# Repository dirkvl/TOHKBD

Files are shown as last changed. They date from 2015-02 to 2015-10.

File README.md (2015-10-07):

# TOHKBD rev2

## History

When Jolla announced their [Jolla phone](https://www.youtube.com/watch?v=tRZxM9rNyZ4) the mobile Linux community rejoiced and finally had a place to go from their N8x, N900, N950 or N9. Together with the new operating system on the inside, the OtherHalf concept was introduced. With direct data-connection into the phone it is now possible to extend the functionality on a hardware level.

Naturally, a keyboard OtherHalf was the [most requested feature](http://www.jollatides.com/2013/10/03/other-half-lets-prioritise/) by the community by far. Jolla however was still getting started and getting their phone launched with the minimum of Sailors at the time. This was left to the community to develop.

In [June 2013](http://talk.maemo.org/showthread.php?t=91535) one idiot thought he could easily make this -how hard could it be, really?- and started on his journey. After some time this foolish individual make TOHKBD-rev1: hackish, ugly, frankensteined, terrible durability and way too much work to assemble. But it worked. 

After this project ended there was a period of other Funky-TOH development, with during that time a lot of requests of making more keyboards. Little did they knew that in the background the imfamous 'dirkvl' together with his trusty 'kimmoli' were cooking up a new version. A better one. The One.

With an [open application](https://twitter.com/andrewzhilin/status/493485714798313472) on the hashweb/tweetspace Andrew joined the team and provid himself to be the missing piece of the three piece puzzle. With a complete team, a solid design and a strong backing from the rest of the community, the TOHKBD-team set out onto the open crowdfunding sea. [And struck gold.](https://www.kickstarter.com/projects/2028347278/tohkbd-the-other-half-keyboard-for-your-jolla)

## Hardware

### Electronics

#### TOH-cover

In the cover that snap onto the phone there is very little going on. There is a PCB that connects to all [6 pogo-pins](https://jolla.com/the-other-half-developer-kit/). Connecting to these pins is a [voltage regulator](https://github.com/dirkvl/TOHKBD/tree/master/Eagle/pics/MCP1703.jpg) and an EEPROM. 

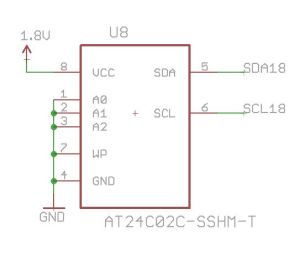
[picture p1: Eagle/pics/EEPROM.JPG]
EEPROM


This is a memory module that contains a [Vendor and Product ID](https://wiki.merproject.org/wiki/The_other_half). The phone reads this EEPROM when it connects to start the appropriate driver.

If the driver is not installed, the phone reads the [NFC tag](http://www.nfcnetstore.com/SMARTRAC+Midas+NTAG203+12x19+mm+clear+%28NFC+Forum+Type+2%29/p/121/) on the PCB and pulls the driver from the store.

With two contact pads (8mm PCBs) the keyboard piece can make contact, all 6 pins are available.

#### Keyboard piece

In the keyboard a little more is going on. The main driver is the [TCA8424](http://www.ti.com/product/TCA8424/description). It runs on 1.8V I2C lines and has three notification LEDs connected, where the TCA8424 acts as an open drain. The LEDs have some probing pads for testing during production.

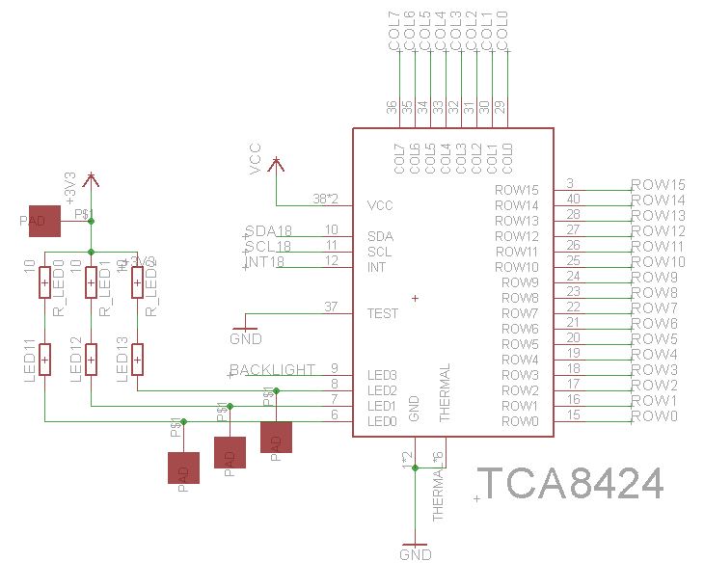
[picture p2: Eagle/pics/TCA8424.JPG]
TCA8424


This connects to the keyboard matrix. It waits untill a key is pressed, then starts scanning and notifies the phone via the INT pin that is has data to be read.

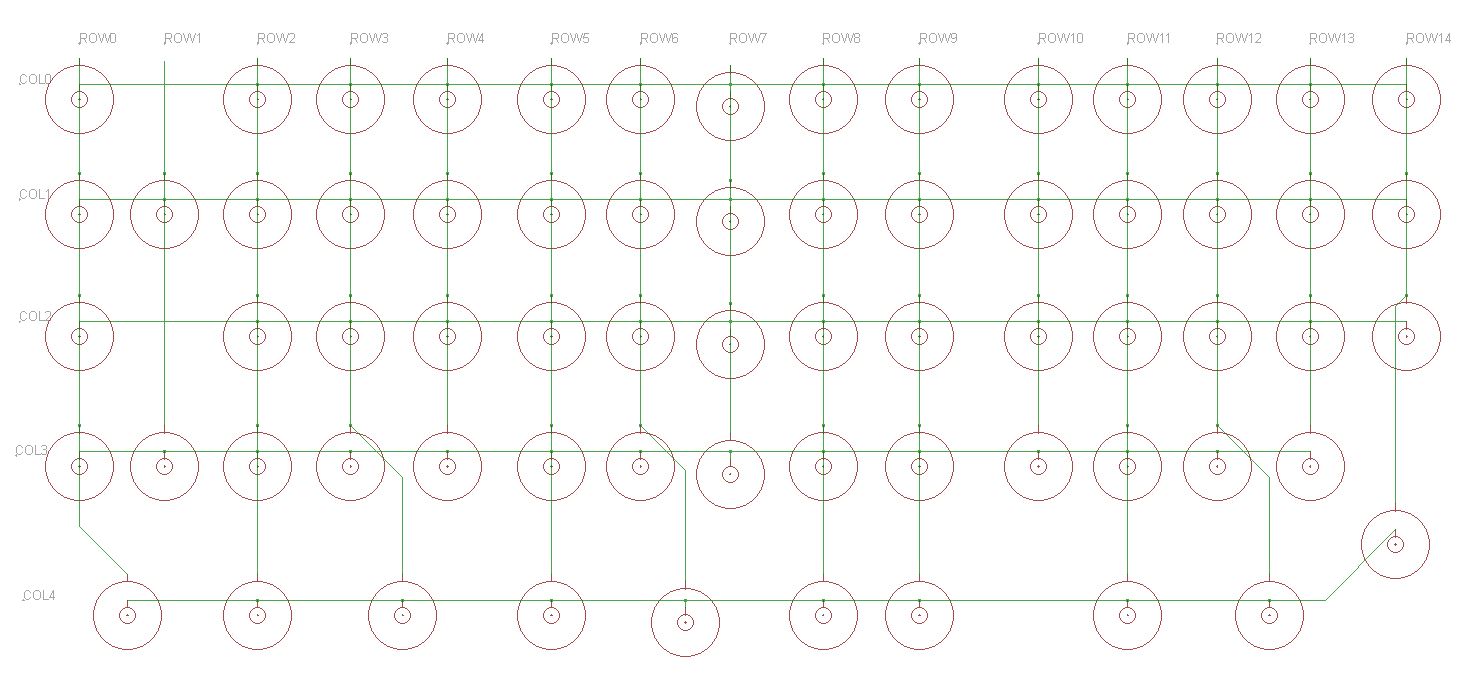
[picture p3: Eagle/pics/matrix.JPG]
Keyboard matrix


There is an additional EEMPROM in the keyboard piece, containing the keypad layout version. The A0 address pin is pulled high to make it shift one address place and not conflict with the EEPROM in the TOH-cover.

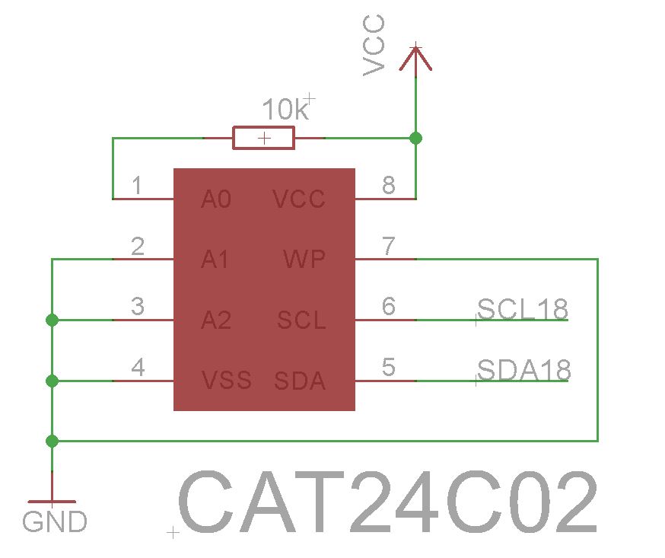
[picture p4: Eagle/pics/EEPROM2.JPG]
Keyboard EEPROM


The backlight consists of 10 x 0402 LEDs, controlled with a [n-channel MOSFET](http://en.wikipedia.org/wiki/MOSFET) by the TCA8424.

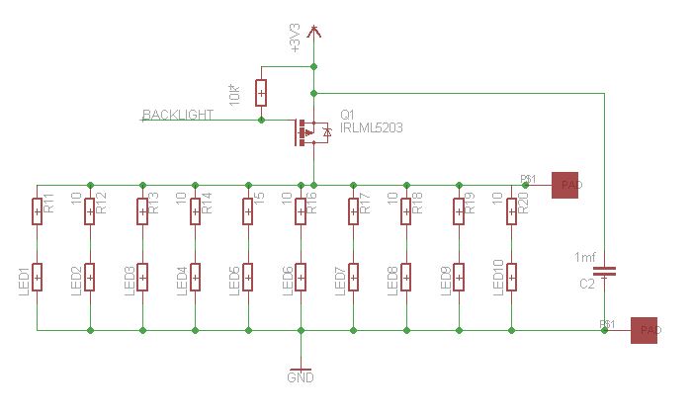
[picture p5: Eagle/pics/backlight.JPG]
Backlight


The keyboard detection is done with a PNP transistor.

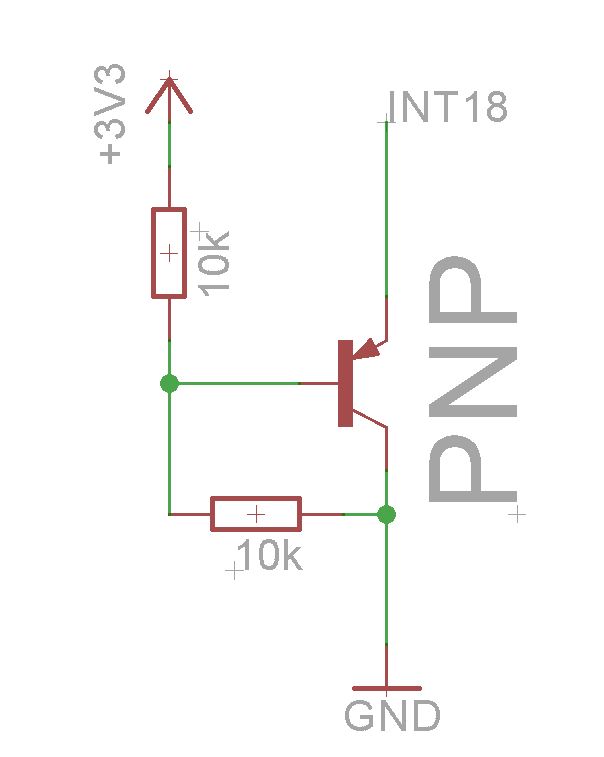
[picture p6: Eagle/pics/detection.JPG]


```
1. Phone detects TOH-cover
2. Phone launches TOHKBD driver
3. The driver shuts down the 3V3 line and starts listening to the interrupt
4. When the keyboard connects, the PNP transistor shorts the interrupt line to ground
5. The phone detects the grounding of INT and powers up de 3V3 line
6. The 3V3 disables the grounding on INT in the transistor
7. The phone probes whether the TCA8424 is present
8a. If the TCA8424 is present, the keyboard is present and working and all is set in motion
8b. If the TCA8424 is not present, something is wrong and the phone goes back to step 3
```

SMD part list:
```
TCA8424 - QFN40
CAT24C02 - DFN6
IRLML5203 - SOT-3
10K pullup/downs - 0603
10R led resistors - 0603
MCP1700 - SOT-3
0.1uF 6V capacitors - 0603
3.15V highbright leds - 0402
Pogo pins - Mill-Max 0906-0-15-20-76-14-11-0 (Mouser P/N: 575-906015)
```

### PCBs

Made in Eagle Cadsoft. The gerber files are linked below:

[Cover PCB](https://raw.githubusercontent.com/dirkvl/TOHKBD/master/Eagle/Cover.rar)

[Keyboard PCB](https://raw.githubusercontent.com/dirkvl/TOHKBD/master/Eagle/Keyboard.rar)

### SMD assembly

The first step in SMD assembly is applying solder past on the PCB with a stencil printer.

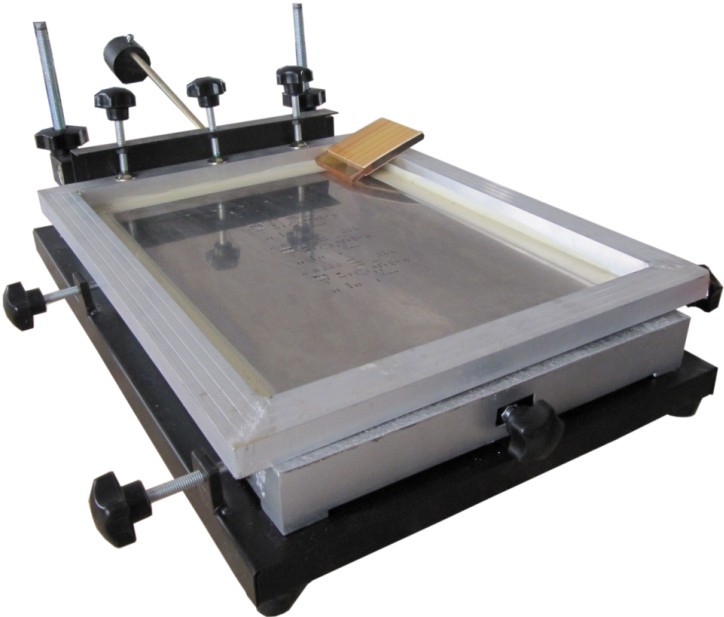
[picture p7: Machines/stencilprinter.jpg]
Stencil printer


Next a pick&place machine puts the components in the right place on the PCB. I use a TM220A.

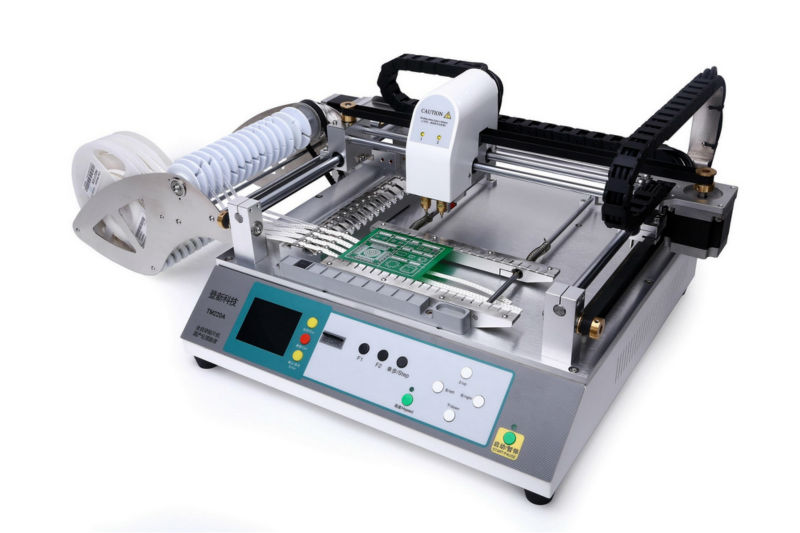
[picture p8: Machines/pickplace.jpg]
Pick & Place


Because the accuracy of the machine it not astronomical, the allignment of every component is checked and adjusted by hand if neccessary. 

The solderpaste is melted in a reflow oven. (T-962A)

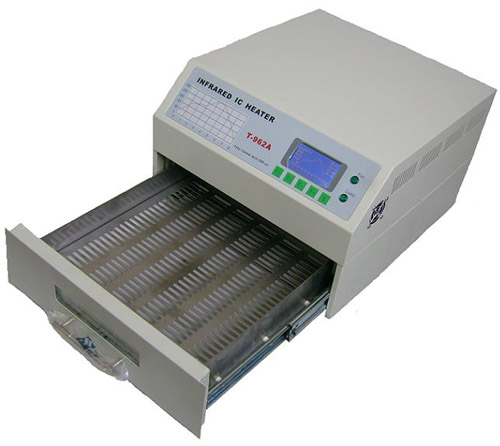
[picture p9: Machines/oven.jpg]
T962A


Lastly the PCB is tested manually and all shorts are corrected with a soldering iron.

### Frames

The frames are 3D printed (using a process called lasersintering) by Shapeways. If you want to change the colour of your TOHKBD, you can order one of these parts from them:

Cover link
Keyboard link

### Magnet system

The keyboard part uses magnets to attach and detach in all positions. 

The magnets used are the [D61-N52](https://www.kjmagnetics.com/proddetail.asp?prod=D61-N52) and [D62-N52](https://www.kjmagnetics.com/proddetail.asp?prod=D62-N52) from KJMagnetics.

<insert picture with dimensions>

### Keypad

Credits to Andrew

### Layouts

designs, files etc

### Backplate

<Dimensions>

## Software

[Link to Kimmoli's Github](https://github.com/kimmoli/)

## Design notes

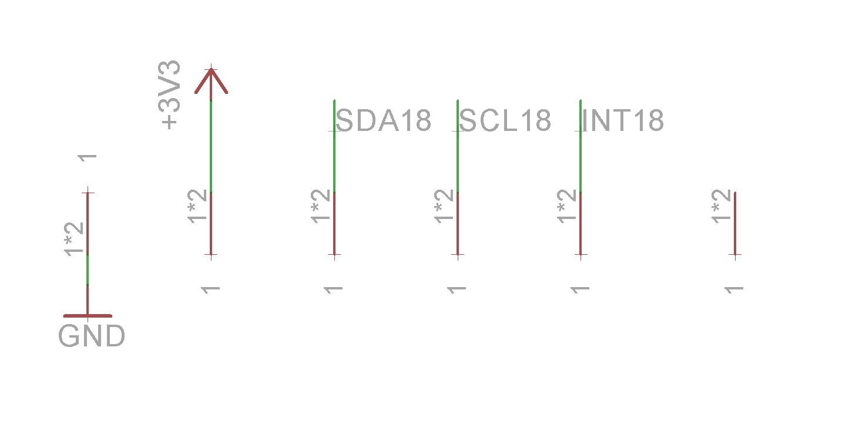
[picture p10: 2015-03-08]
Eagle/pics/pogopins.JPG

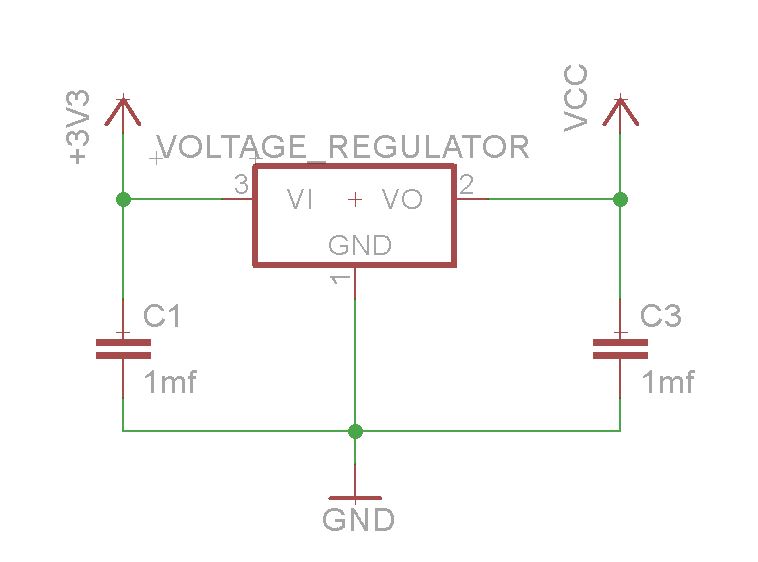
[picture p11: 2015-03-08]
Eagle/pics/MCP1703.JPG

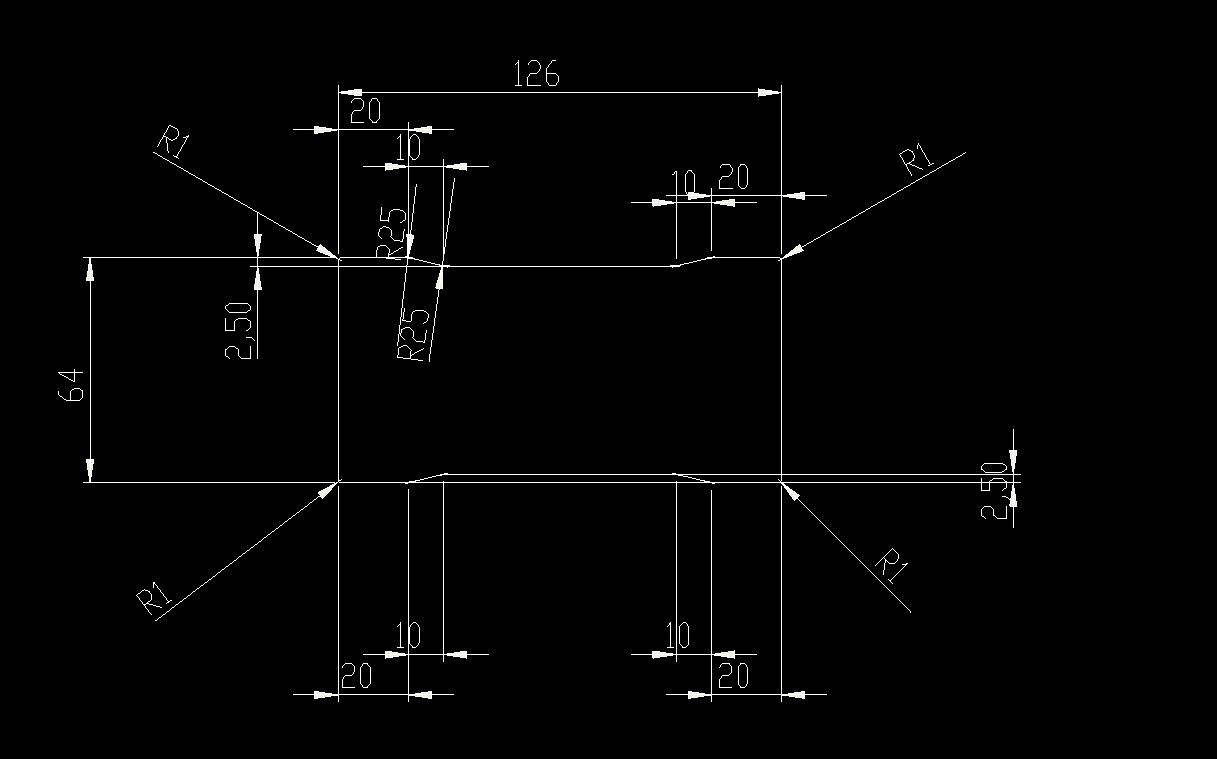
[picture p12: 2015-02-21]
Backplate/Backplate.JPG

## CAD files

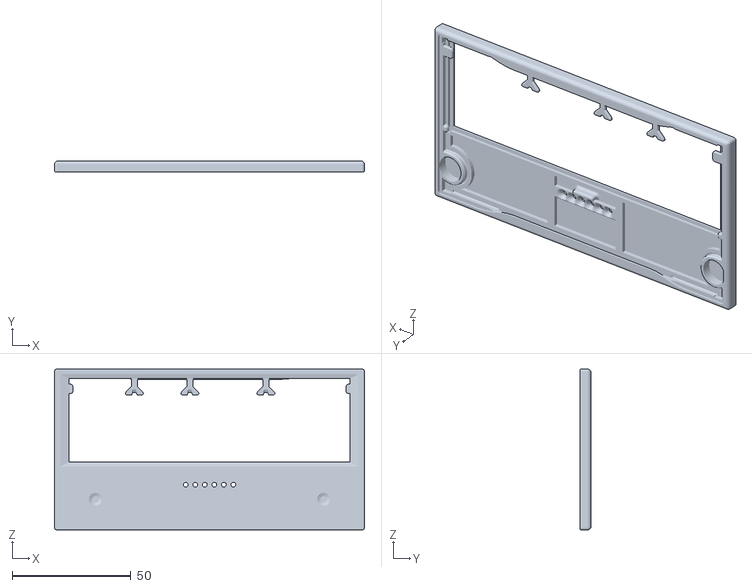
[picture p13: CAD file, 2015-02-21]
CAD/Keyboard.STL
130.4 x 4.70 x 67.7

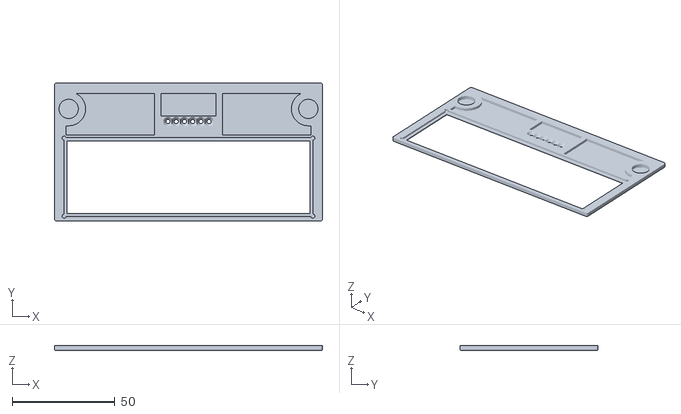
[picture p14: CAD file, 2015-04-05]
DIY specific/FDM printer compatible 3D models/KBD_top.stl
130.4 x 67.3 x 2.30

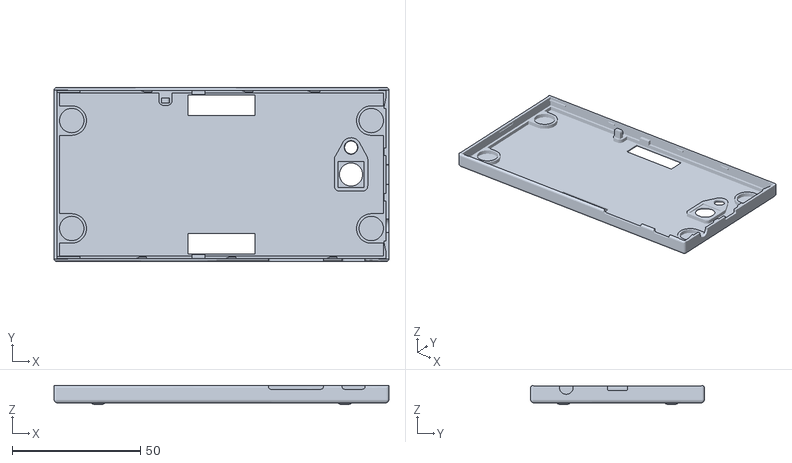
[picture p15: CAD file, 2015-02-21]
CAD/TOH_casing.STL
130.4 x 67.7 x 7.50

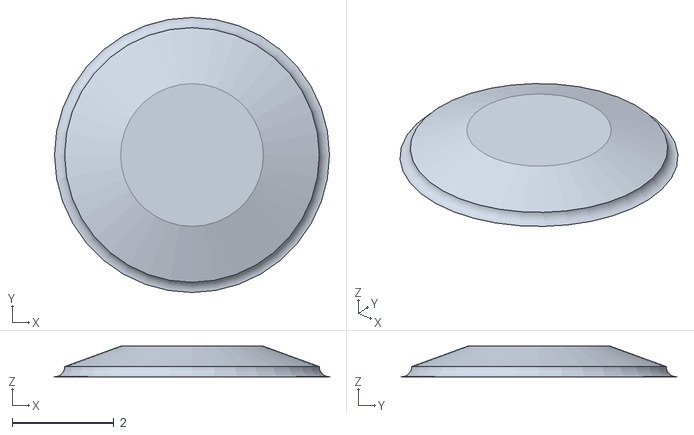
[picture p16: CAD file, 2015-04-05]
DIY specific/FDM printer compatible 3D models/bump.stl
5.40 x 5.40 x 0.6

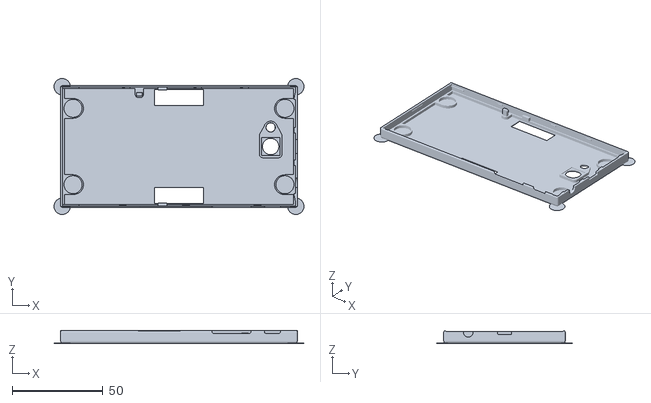
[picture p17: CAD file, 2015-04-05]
DIY specific/FDM printer compatible 3D models/casing.stl
137.5 x 74.8 x 6.90

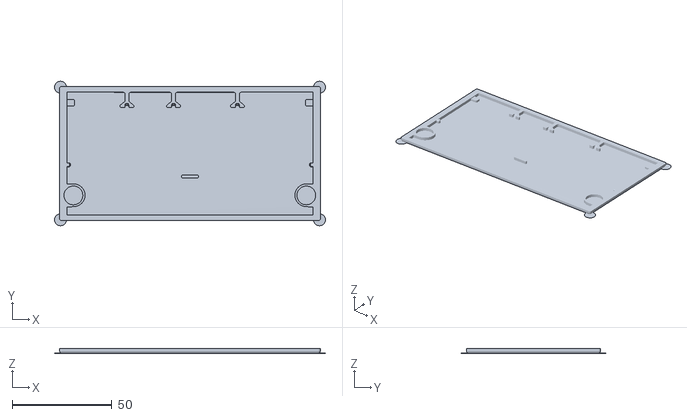
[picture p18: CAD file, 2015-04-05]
DIY specific/FDM printer compatible 3D models/KBD_back.stl
135.7 x 72.4 x 2.44

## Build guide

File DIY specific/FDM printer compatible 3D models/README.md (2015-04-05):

# FDM printer compatible versions of the TOHKBD casings
## Keyboard casing
The keyboard casing was split in to two objects to get rid of the overhanging parts. Note that the original magnets that came with the DIY kit probably do not fit the magnet holes any more as it is now designed for a bit smaller diameter magnets.

## TOH casing
The alignment bumps were removed from the casing that attaches to the phone and the long side walls were made thinner to not cover the power and volume rocker buttons as much as the original model.

## Assembly demo video
https://youtu.be/Ag15Dl4L8tw

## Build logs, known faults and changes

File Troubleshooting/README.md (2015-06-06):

# Troubleshooting

## Regular mode of operation

Connect Cover to phone. Phone should read EEPROM to check if driver is already installed, if not it will pull it from the store with the ID found on the NFC tag. Connecte the keyboard, it should say 'keyboard connected' as a notification. You are ready to rock and roll now!

At this moment, the NFC tag is NOT linked to the store, so it will say 'This OtherHalf does not work'. This does not mean it is broken, it just can't find the driver. You can fix this by waiting untill it is linked, or install it yourself from [Kimmo's Github](https://github.com/kimmoli/tohkbd2).

## Troubleshooting flowchart

- insert epic flowchart -

## Checking Cover PCB

## Adjusting Cover casing

## Checking connector pads

## Checking pogo pins

## Checking keyboard PCB

## Adjusting keyboard casing

## Disassembling and replacing Cover

## Disassembling and replacing Keyboard

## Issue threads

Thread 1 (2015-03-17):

Include FDM printer compatible 3D models

Wnt, 2015-03-17:
The current CAD files are optimized for printing by Shapeways service and are not really useful for home printers

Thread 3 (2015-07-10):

My TOHKBD stopped working

xoquox, 2015-07-10:
Hello,
my TOHKBD stopped working.
I tested all the contacts and it looks like everything is fine with the TOH. The EPROM on the TOH works, and it reinstalls the software.
So i looked up the harbour-tohkbd2 service. All starts fine, but when i put on the Keyboard, it gives me this message:
Jul 10 22:25:01 Jolla harbour-tohkbd2[12142]: Presence detected, turning power on
Jul 10 22:25:01 Jolla harbour-tohkbd2[12142]: VDD control request - turn on
Jul 10 22:25:02 Jolla harbour-tohkbd2[12142]: Error: reset() failed

So, could it be a problem with the TCA8424 or could it be a software problem?
I tested the TOHKBD on two Jolla's , the keyboard used to work on both befor.

I hope to hear from you soon,
greedings
Christian

dirkvl, 2015-07-10:
What do you get from probing the i2c bus in I2Ctool?

2015-07-10 22:36 GMT+02:00 Christian <notifications@github.com>:

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

xoquox, 2015-07-10:
Probing with I2Ctool gets me [Black] on adresss 04-07 and [Blue] on adresses 50-57
So no ACK on any EEPROM :(

xoquox, 2015-07-11:
I also tested the voltage regulator on the TOH, and it put out 1,8V.  So maybe the EEPROM on TOH stopped working?

dirkvl, 2015-07-16:
ehhh i dont know. send it back and ill fix it. my address is on
funkyotherhalf.com, include a note with the issue and a return address.

dirk

2015-07-11 11:09 GMT+02:00 Christian <notifications@github.com>:

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

Bulkin, 2015-08-14:
Any news on this issue? I have the same problem after a phone reboot.

dirkvl, 2015-08-18:
Huh? You sent it back right? You got no 'it is repaired' mail? :s

2015-08-15 0:42 GMT+02:00 Vasili Bulkin <notifications@github.com>:

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

Bulkin, 2015-08-18:
No, I didn't send it back, I only received it a week ago. Anyway, the EPROM isn't really that important, right? It's just for plug-and-play support.

dirkvl, 2015-08-27:
the eeprom on the casing side is crucial, the eeprom on the keyboard side
not so much

2015-08-19 1:24 GMT+02:00 Vasili Bulkin <notifications@github.com>:

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

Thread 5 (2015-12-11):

nitpick: the SMD part list is missing the PNP transistor

urjaman, 2015-12-11:
schematic says MMBTA56, that correct?

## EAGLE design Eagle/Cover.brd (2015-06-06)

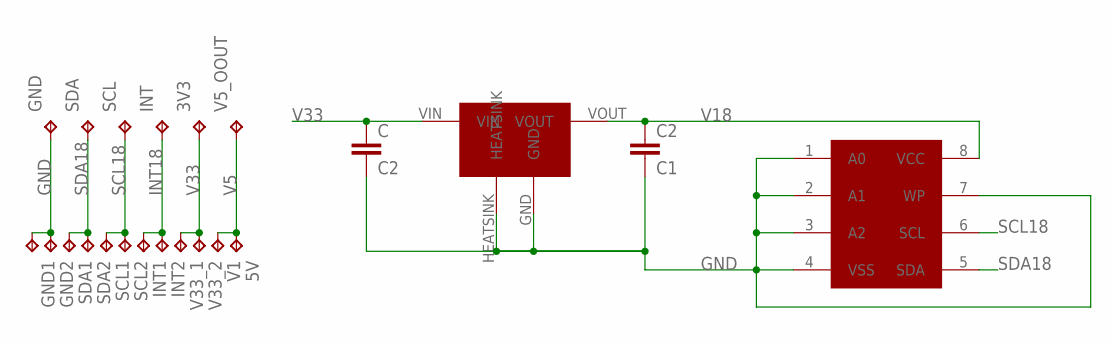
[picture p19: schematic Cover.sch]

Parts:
3V3: TPTP20SQ; TP20SQ
5V: V5; TP20SQ
C: C2; C0603
C2: C1; C0603
GND, GND1, GND2: TPTP20SQ; TP20SQ
INT, INT1, INT2: TPTP20SQ; TP20SQ
SCL, SCL1, SCL2: TPTP20SQ; TP20SQ
SDA: TPTP20SQ; TP20SQ
SDA1, SDA2: SDA; TP20SQ
U$1: CAT24
U$2: MCP1700-DFN6; DFN6-2X2
V1: V5; TP20SQ
V5_OOUT, V33_1, V33_2: TPTP20SQ; TP20SQ

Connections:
GND: C.2, C2.2, GND.TP, GND1.TP, GND2.TP, U$1.1 (A0), U$1.2 (A1), U$1.3 (A2), U$1.4 (VSS), U$1.7 (WP), U$2.GND, U$2.HEATSINK
INT18: INT.TP, INT1.TP, INT2.TP
SCL18: SCL.TP, SCL1.TP, SCL2.TP, U$1.6 (SCL)
SDA18: SDA.TP, SDA1.TP, SDA2.TP, U$1.5 (SDA)
V5: 5V.TP, V1.TP, V5_OOUT.TP
V18: C2.1, U$1.8 (VCC), U$2.VOUT
V33: 3V3.TP, C.1, U$2.VIN, V33_1.TP, V33_2.TP

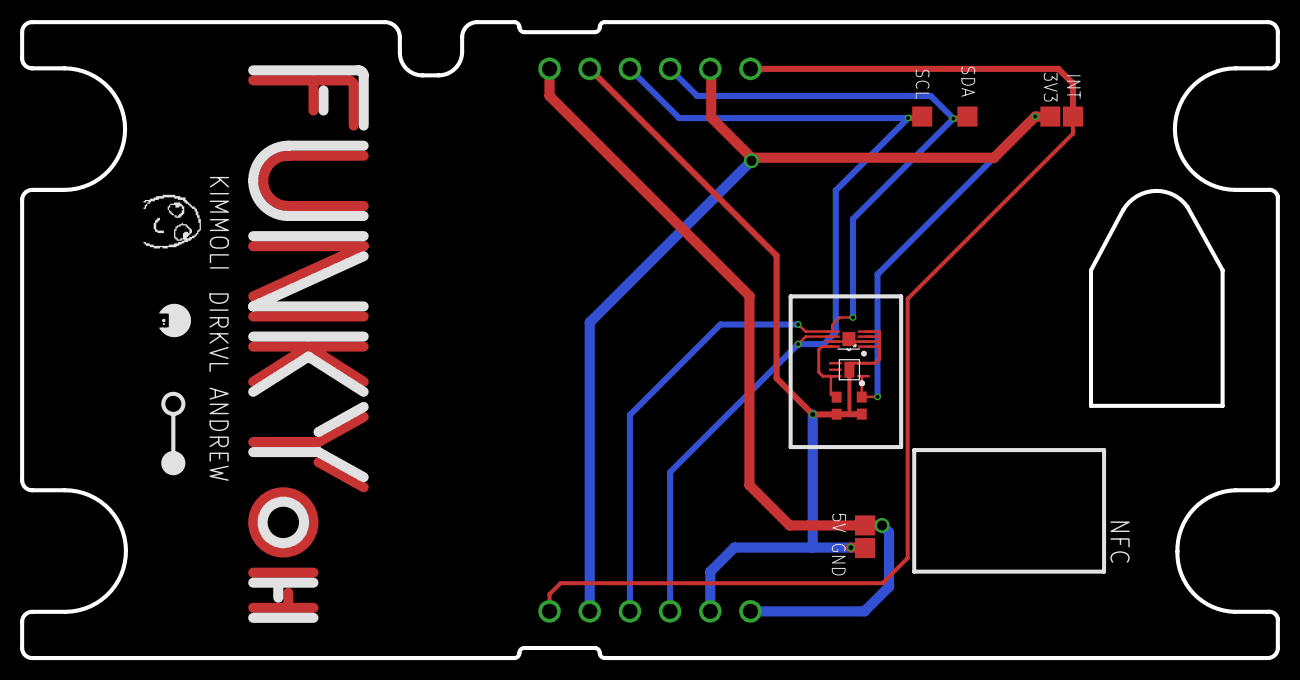
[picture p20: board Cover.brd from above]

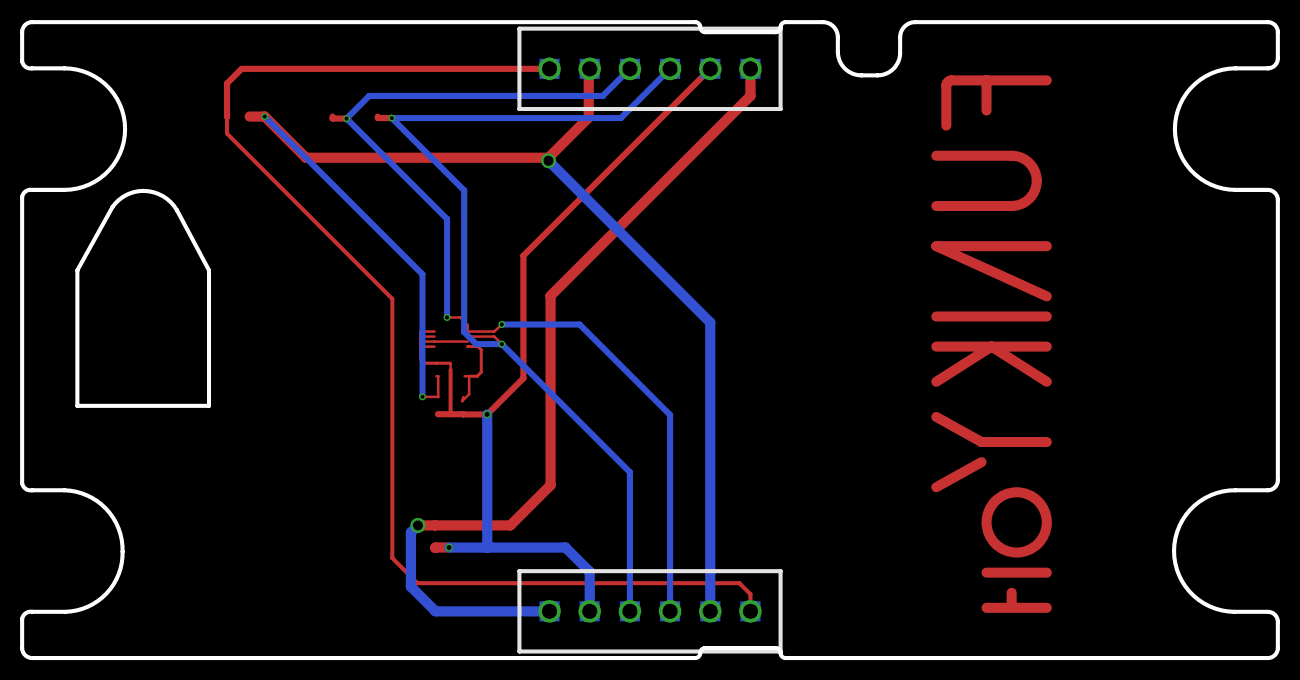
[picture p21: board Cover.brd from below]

Board: 2 copper layers, 125.0 x 63.3 mm, 24 parts (12 on the bottom side), 7 nets.

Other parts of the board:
U$3: FUNKY
U$4: DAFUG

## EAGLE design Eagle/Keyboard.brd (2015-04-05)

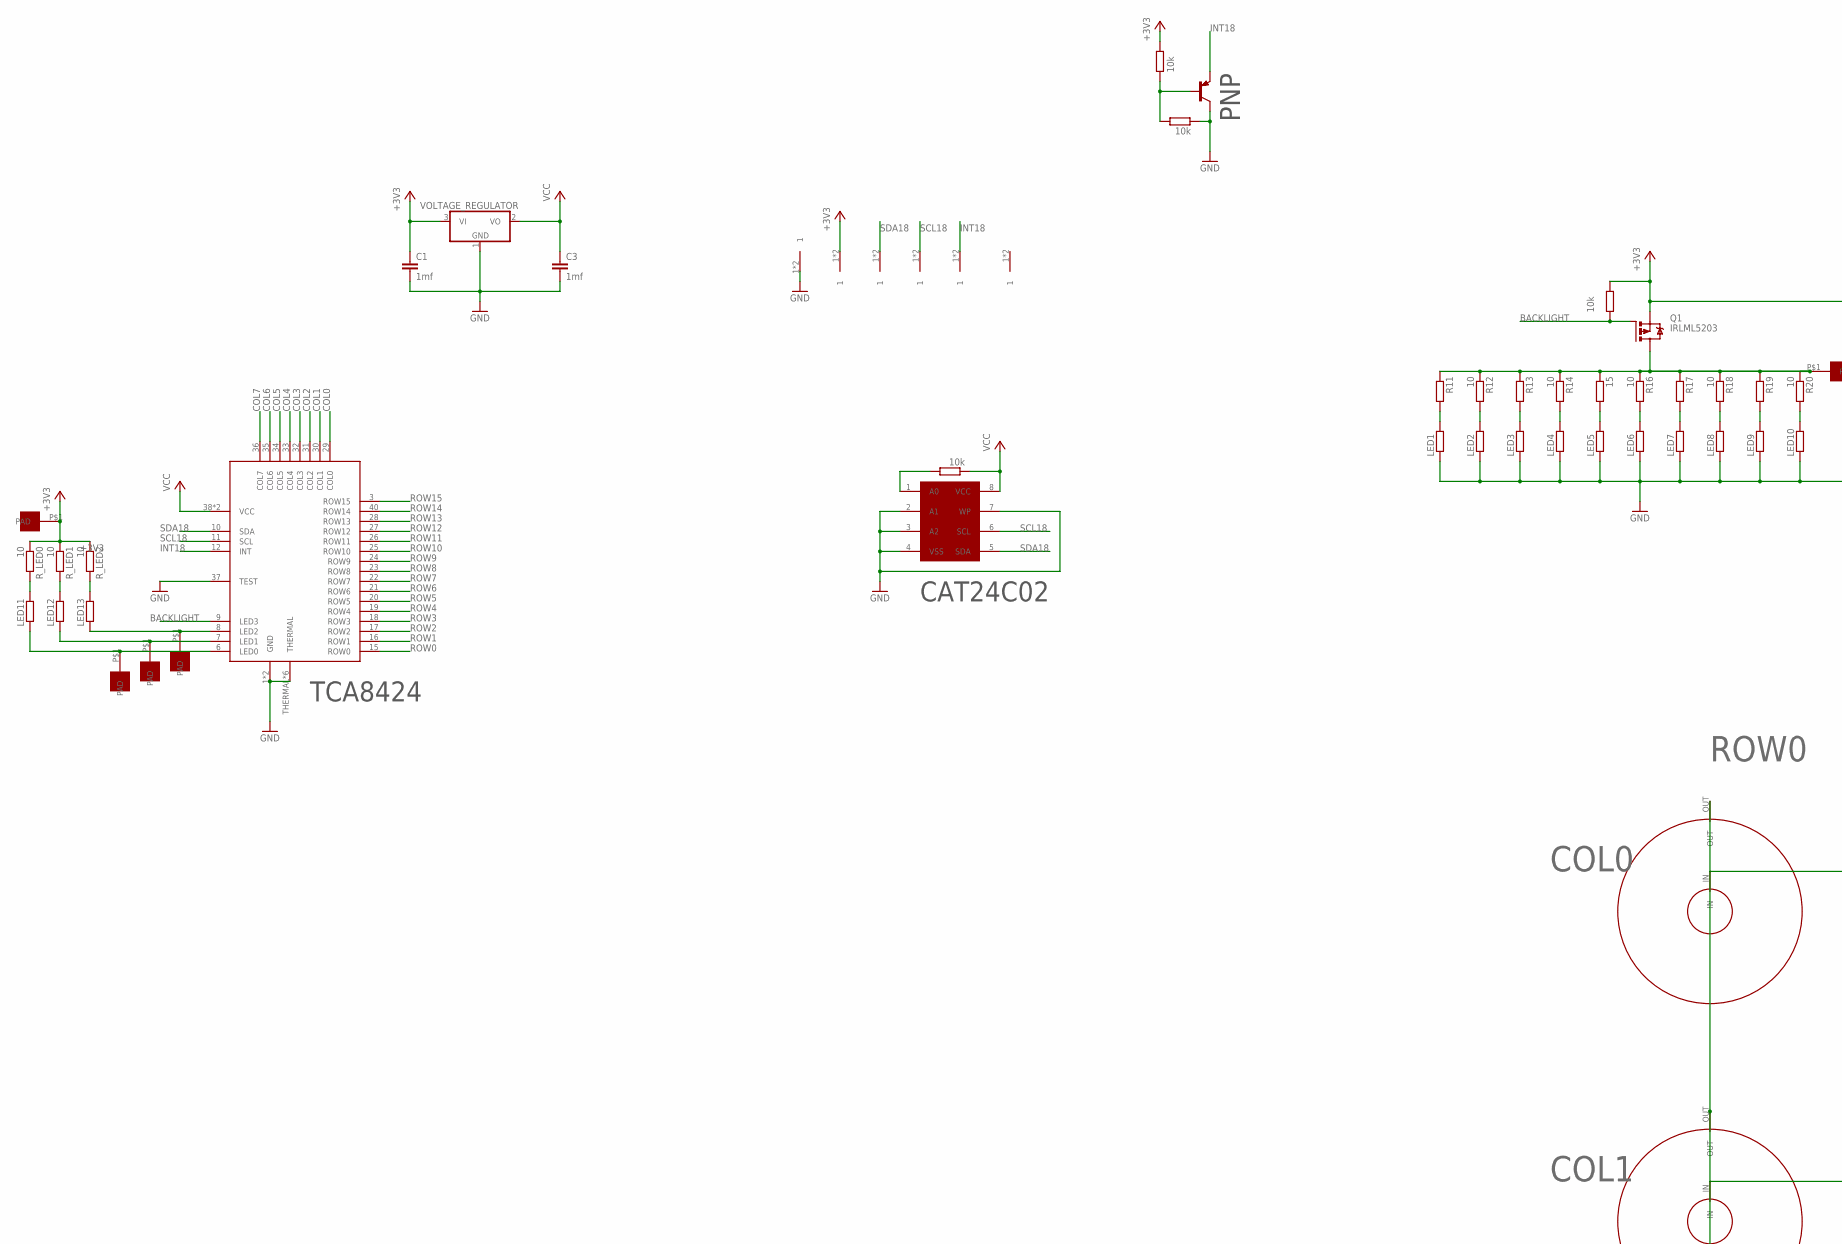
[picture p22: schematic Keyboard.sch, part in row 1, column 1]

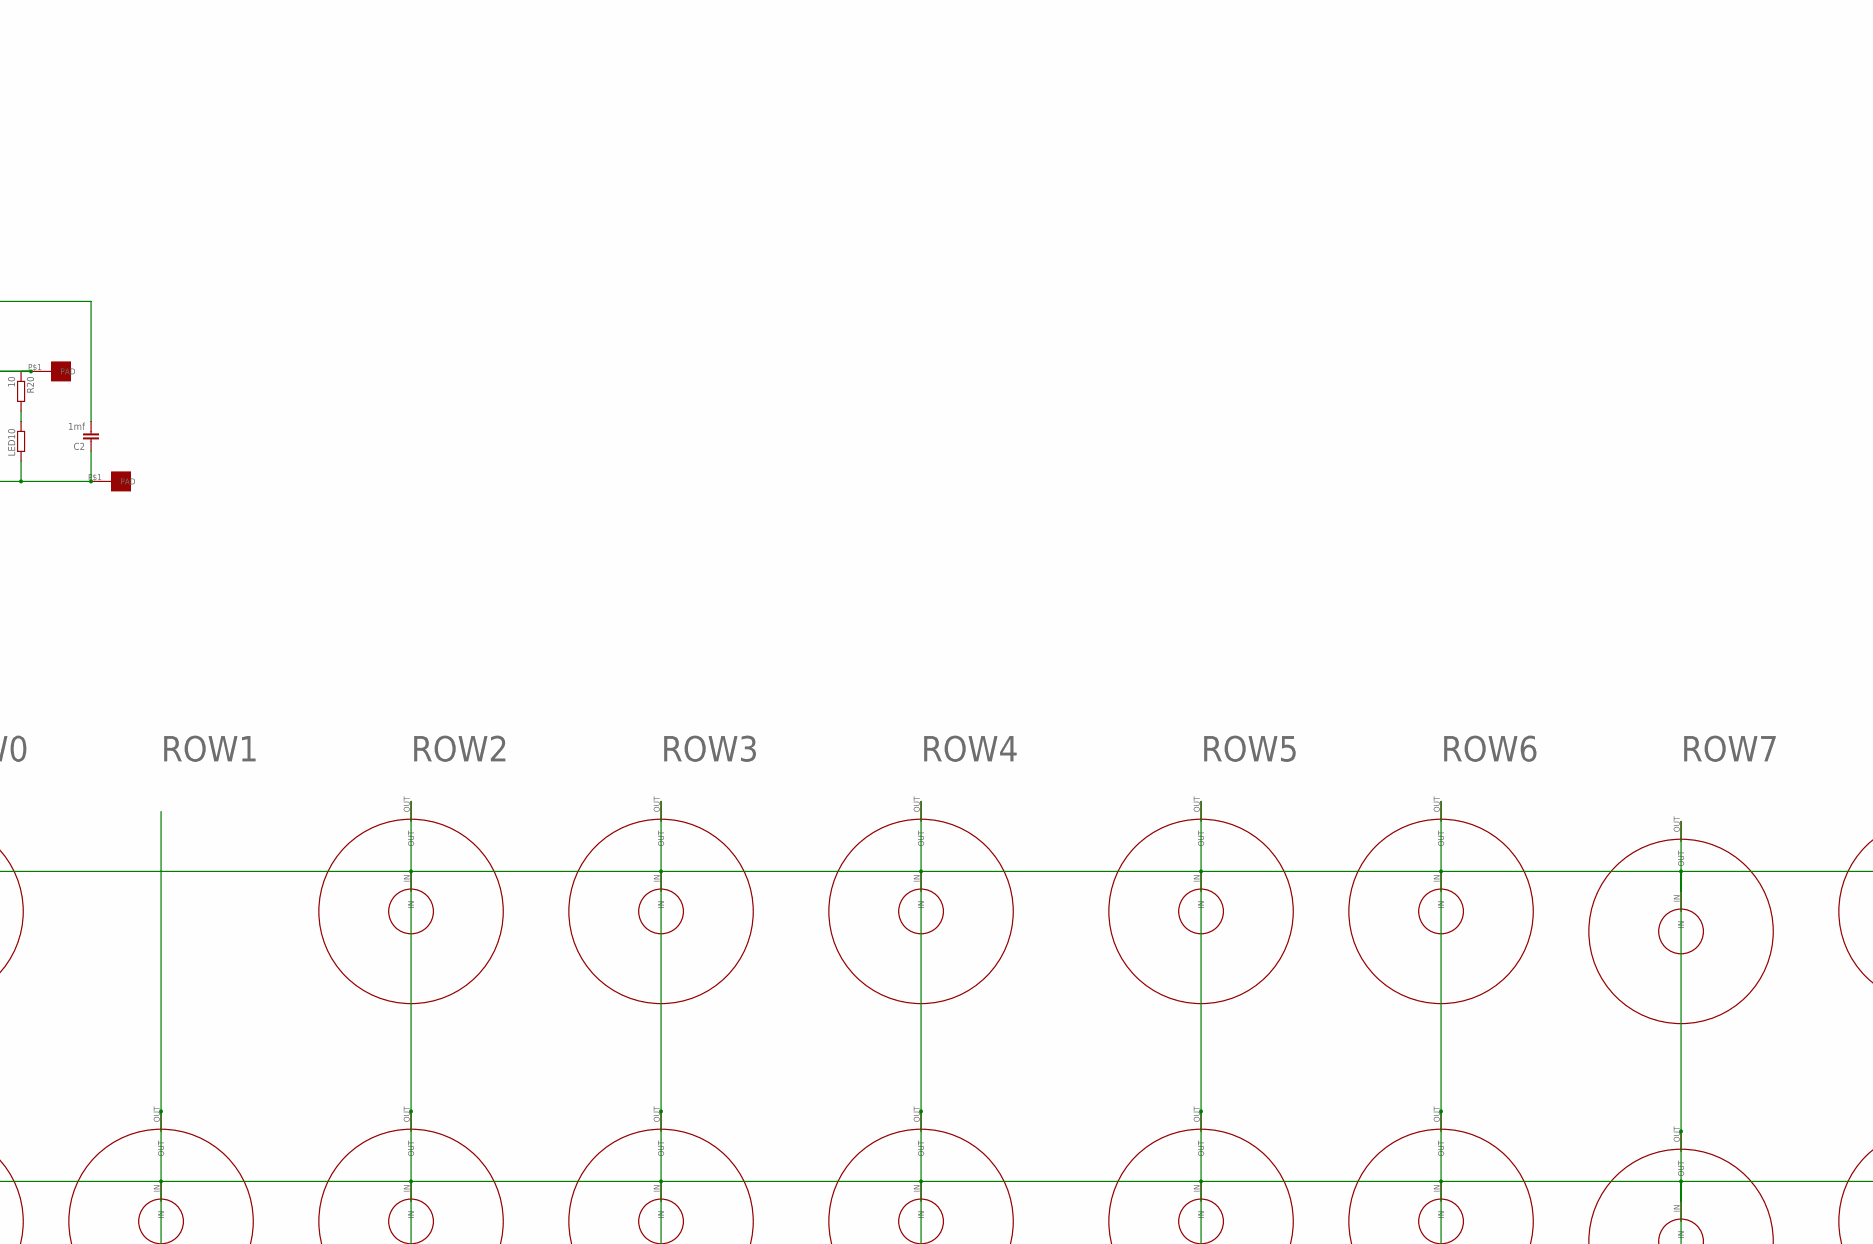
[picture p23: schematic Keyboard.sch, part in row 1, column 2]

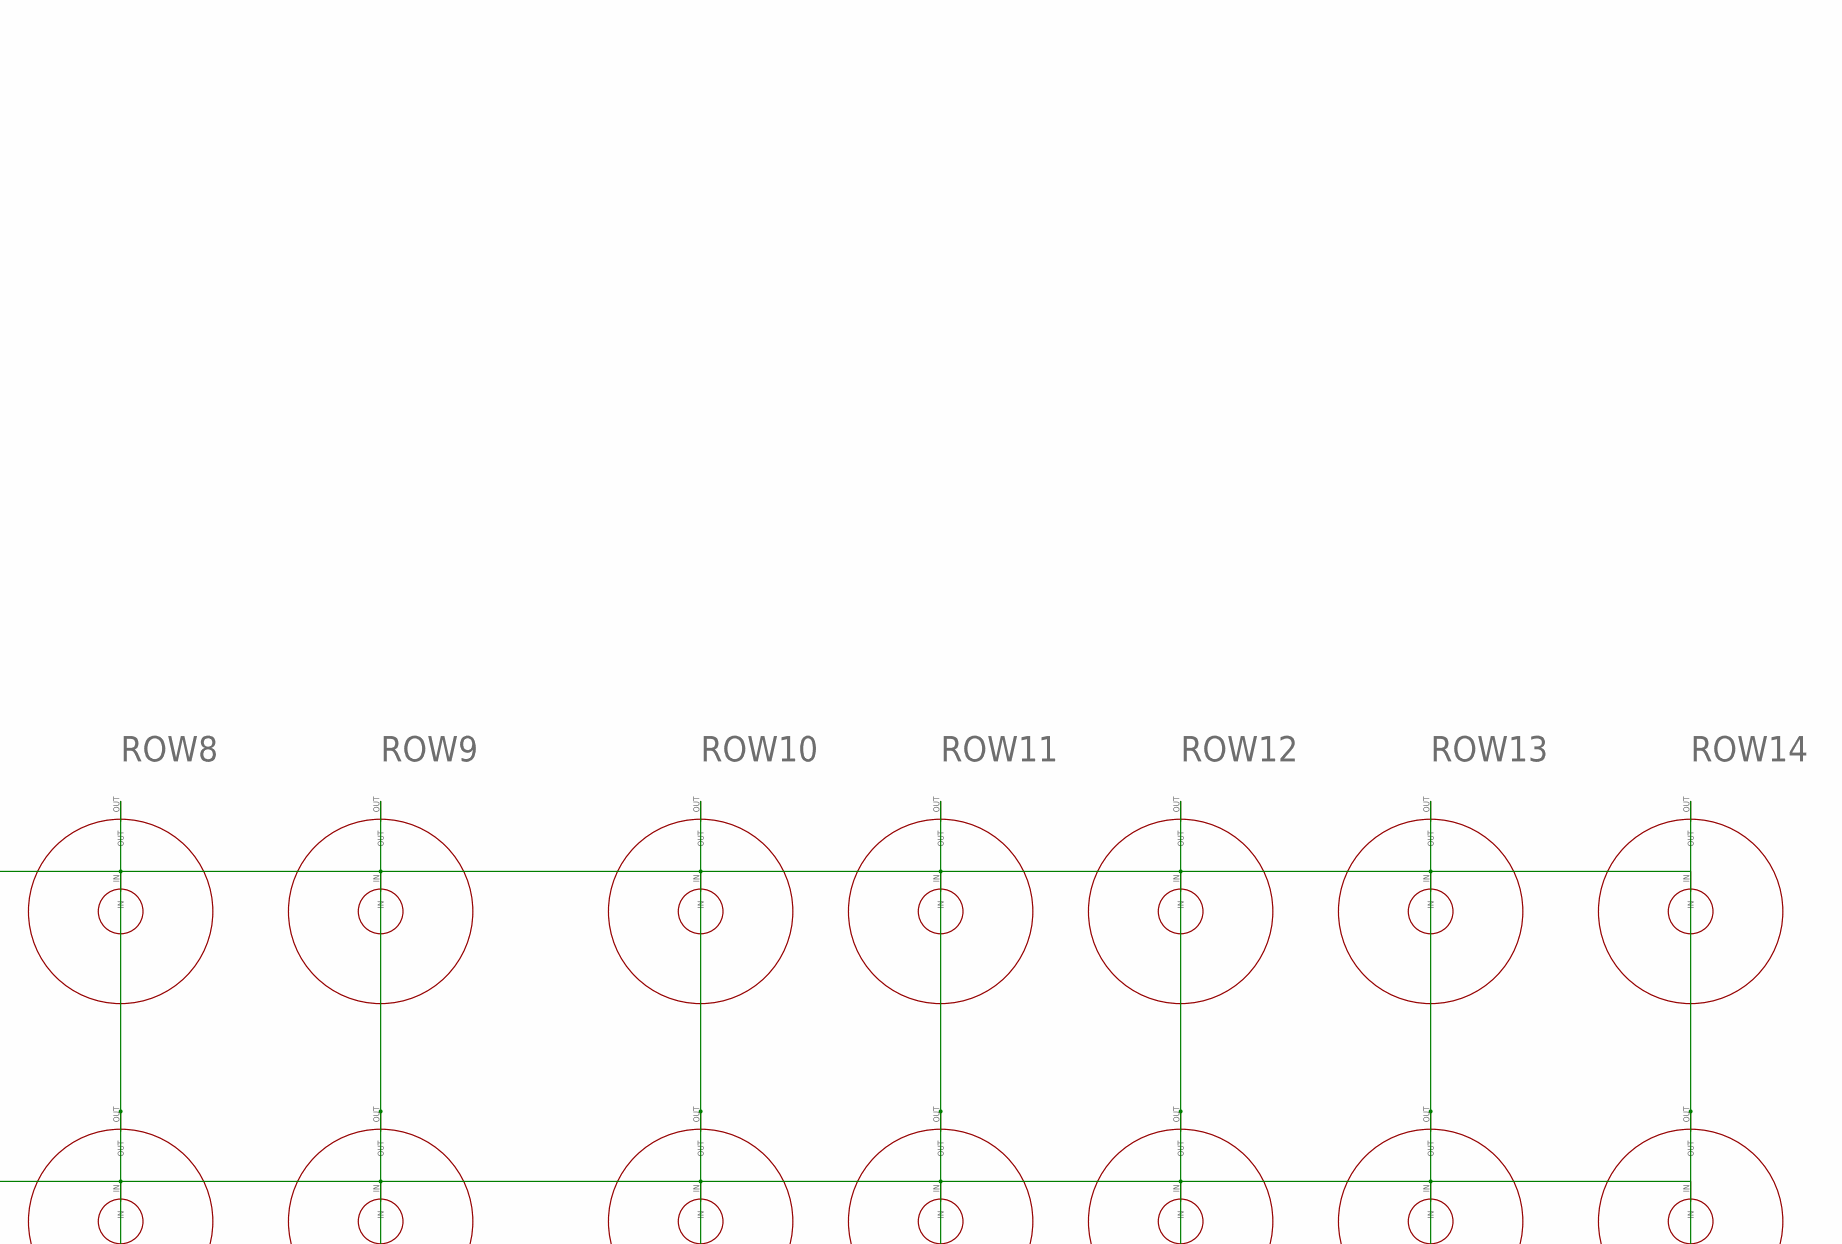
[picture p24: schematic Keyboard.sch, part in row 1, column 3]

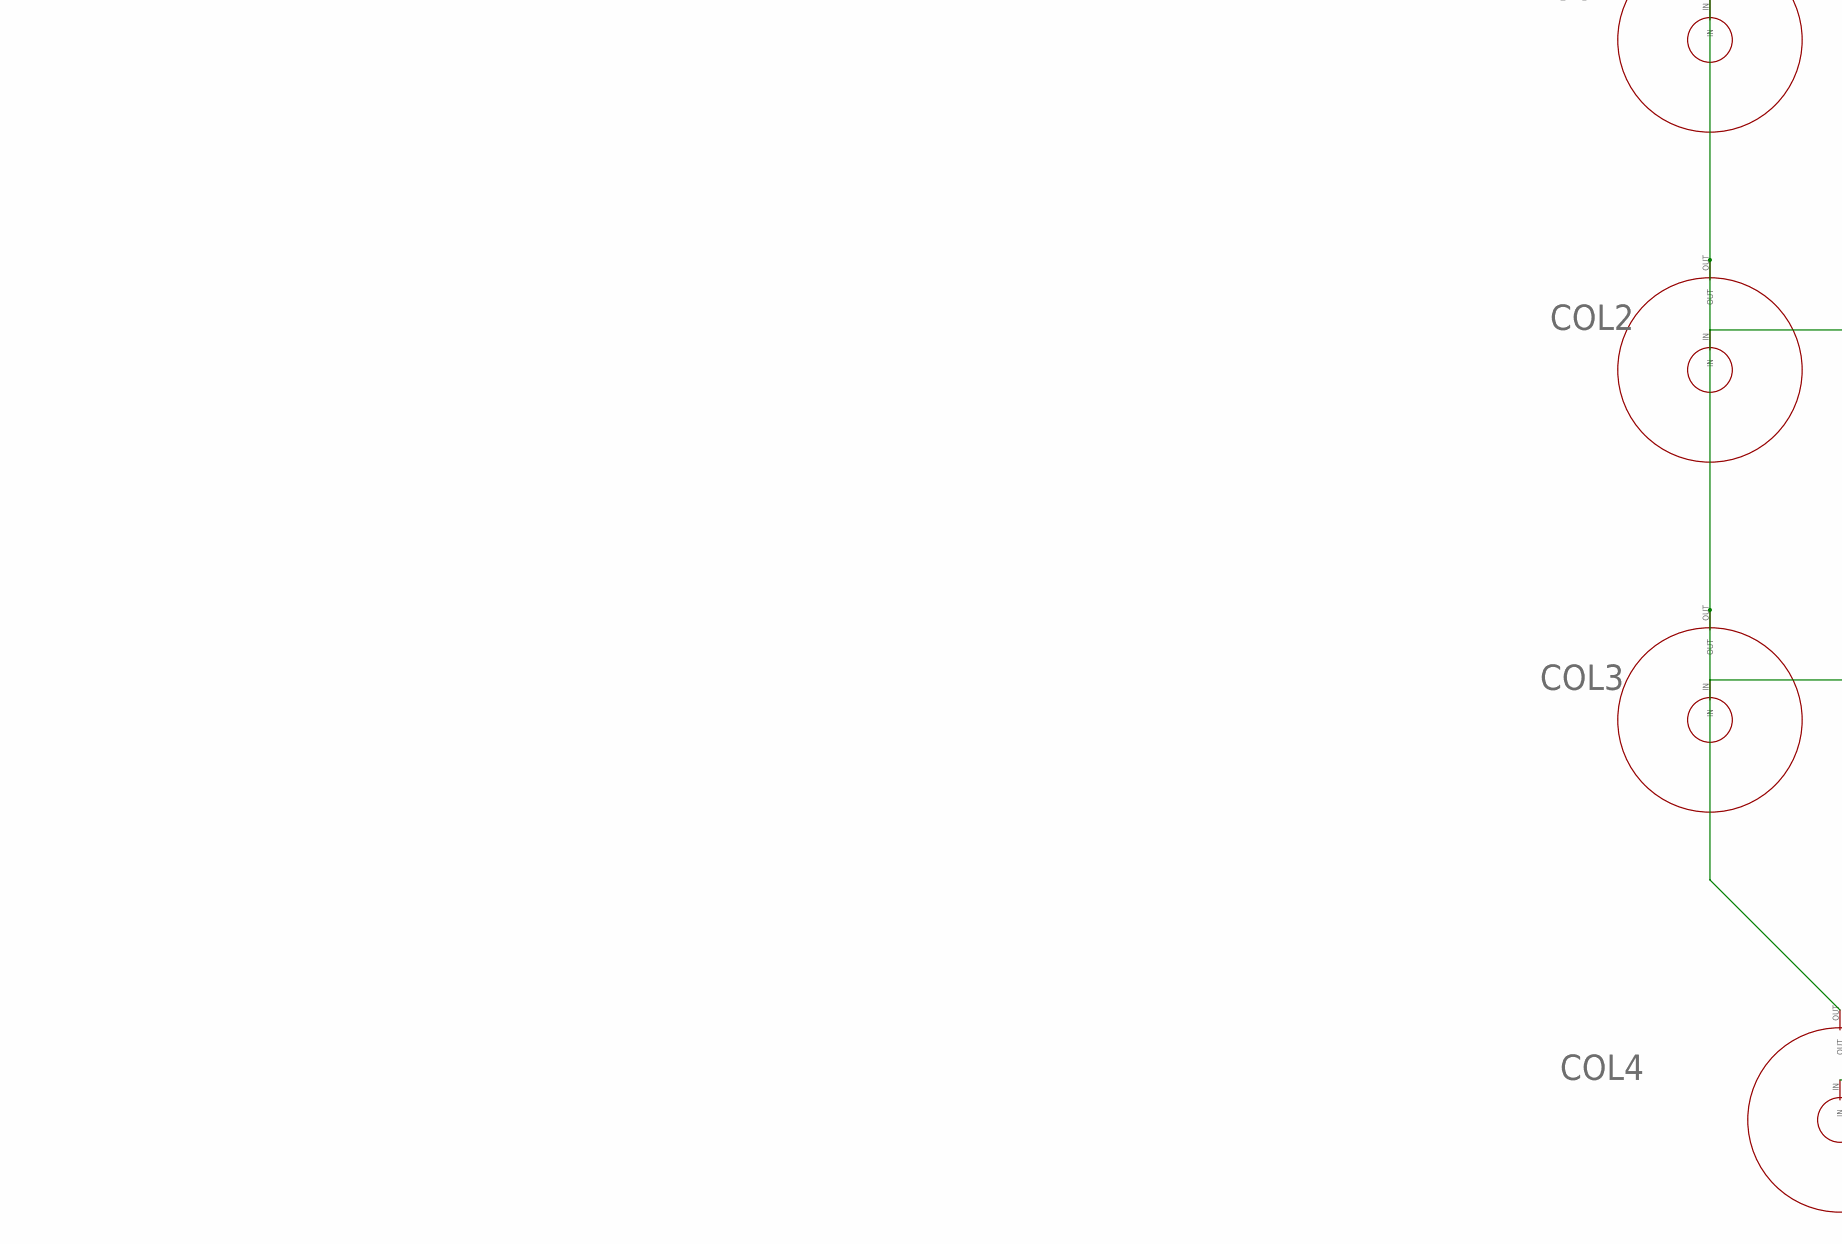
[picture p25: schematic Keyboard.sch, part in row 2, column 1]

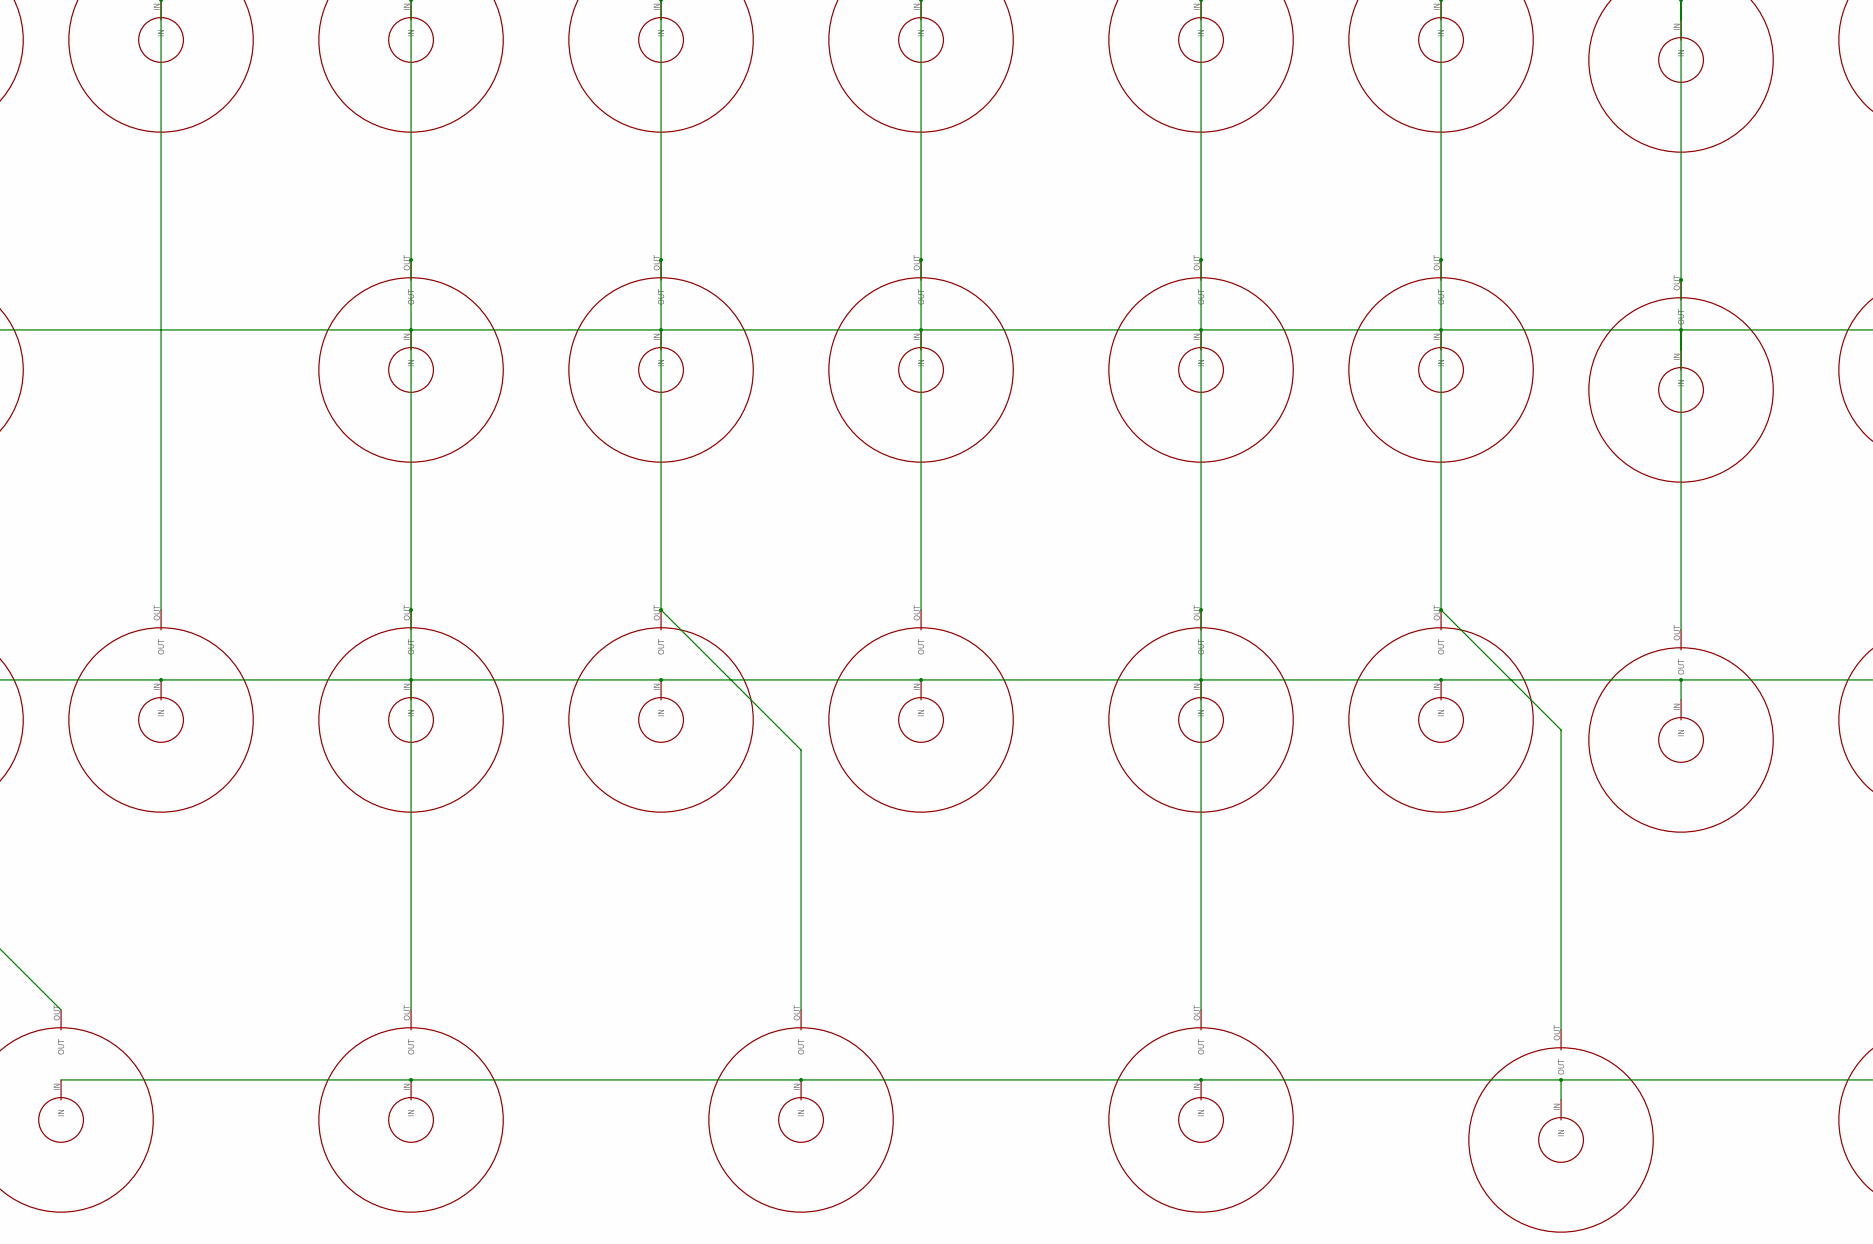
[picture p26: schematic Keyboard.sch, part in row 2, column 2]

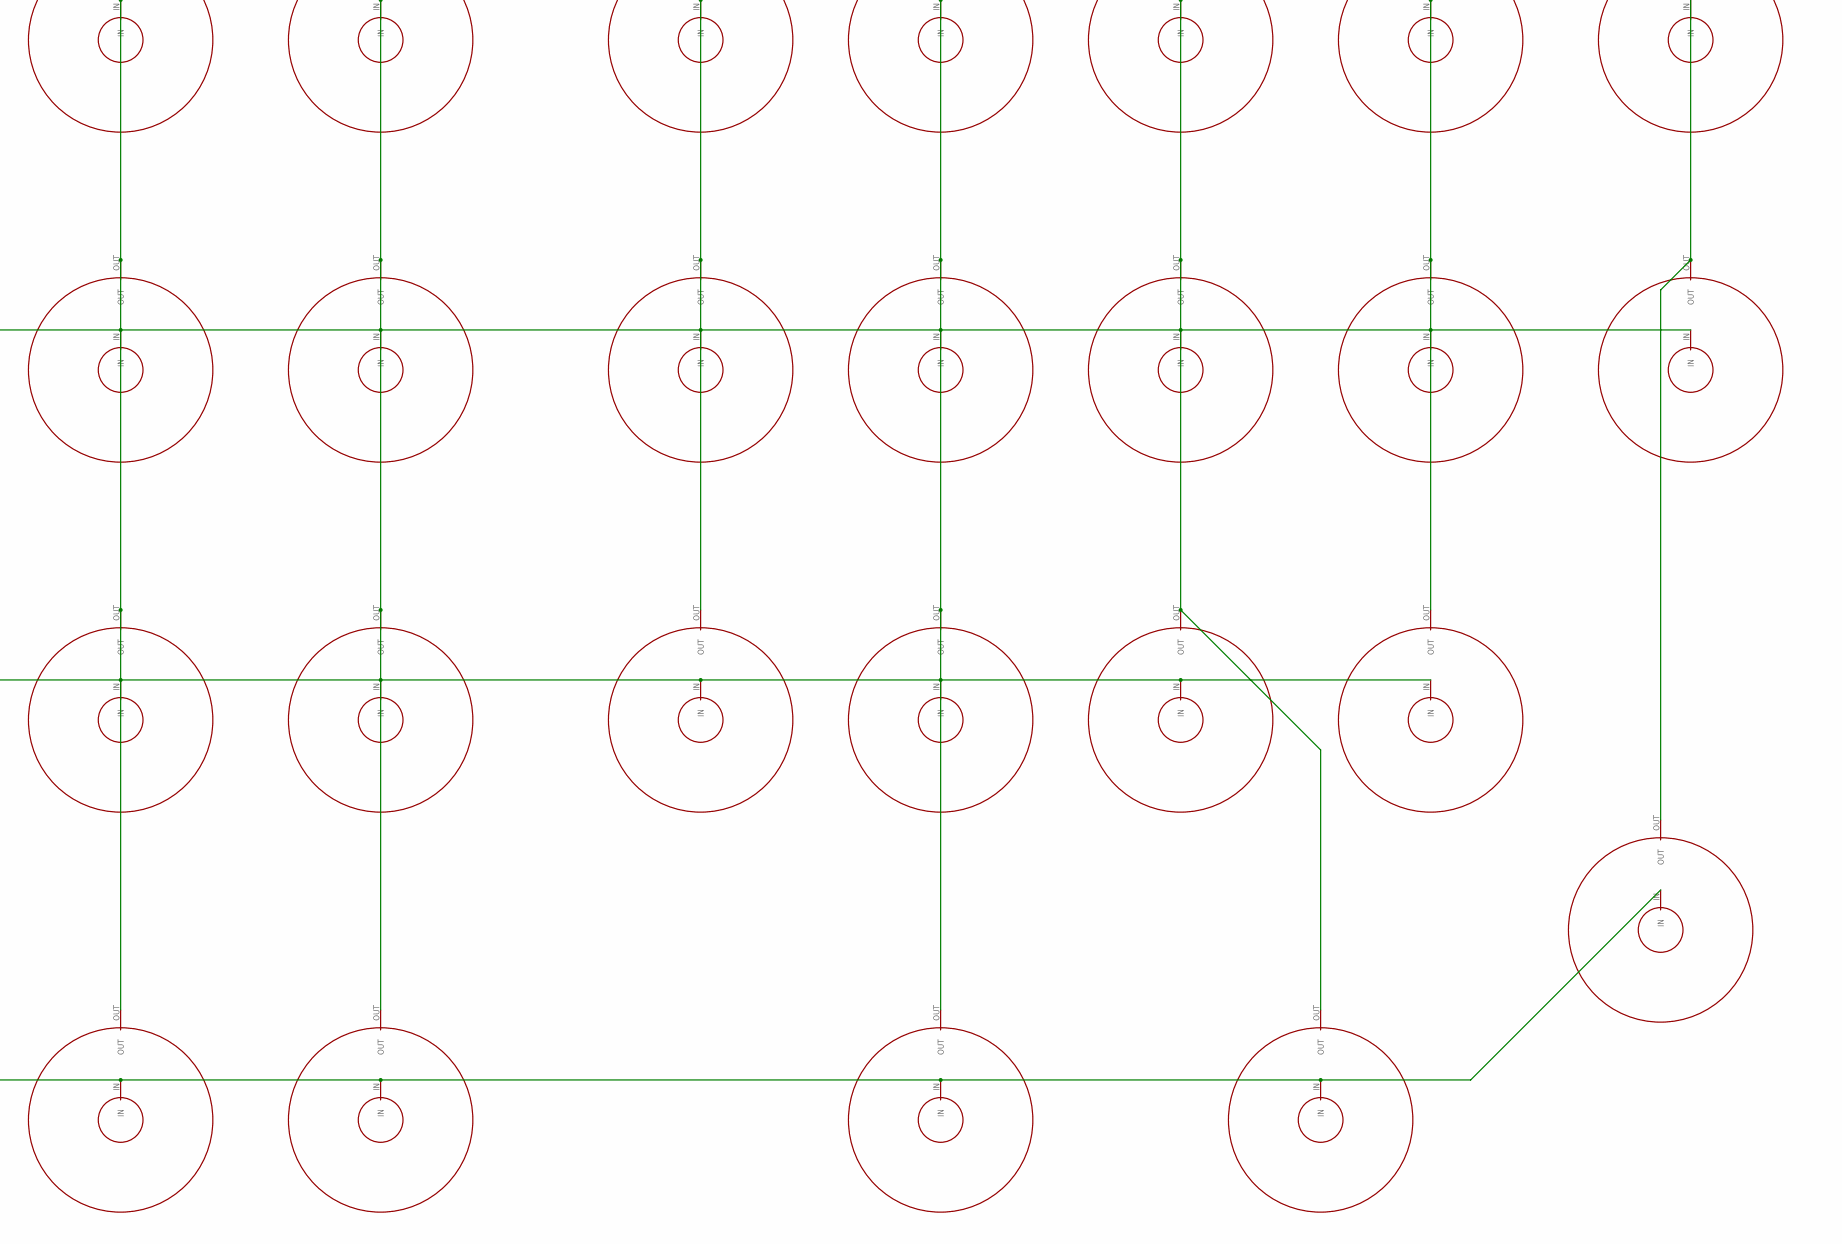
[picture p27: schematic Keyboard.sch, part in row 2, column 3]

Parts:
15: R-EU_R0603; R0603
+: PAD
BL_PULLUP: 10k; R0603
C1, C2, C3: 1mf; C0603
LED1, LED2, LED3, LED4, LED5, LED6, LED7, LED8, LED9, LED10, LED11, LED12, LED13: R-EU_R0402; R0402
PNP_DOWN, PNP_DOWN1: 10k; R0603
PNP_UP: 10k; R0603
Q1: IRLML5203; MICRO3
Q2: MMBTA56-SOT23; SOT23
R11, R13, R17, R19: R-EU_R0603; R0603
R12, R14, R16, R18, R20: 10; R0603
R_LED0, R_LED1, R_LED2: 10; R0603
U$1: CAT24
U$2: TCA8424; QFN40
U$3, U$4, U$5, U$6, U$7, U$8: BOTTOM_POGO; POGO
U$9, U$11, U$12, U$13, U$14, U$15, U$16, U$17, U$18, U$19, U$20, U$21, U$22, U$23, U$24, U$25, U$26, U$27, U$28, U$29, U$30, U$31, U$32, U$33, U$34, U$35, U$36, U$37, U$38, U$39, U$40, U$41, U$42, U$43, U$44, U$45, U$46, U$47, U$48, U$49, U$50, U$51, U$52, U$54, U$55, U$56, U$57, U$58, U$59, U$60, U$61, U$62, U$63, U$64, U$65, U$66, U$67, U$68, U$69, U$70, U$72, U$73, U$75, U$76, U$77, U$79, U$81: DOME; 4MM
U$53, U$71, U$74, U$78, U$80: PAD
VOLTAGE_REGULATOR: SOT23

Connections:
+3V3: +.P$1, BL_PULLUP.1, C1.1, C2.2, PNP_UP.1, Q1.2 (S), R_LED0.1, R_LED1.1, R_LED2.1, U$4.1, U$4.P$2, VOLTAGE_REGULATOR.3 (VI)
BACKLIGHT: BL_PULLUP.2, Q1.1 (G), U$2.9 (LED3)
COL0: U$2.29 (COL0), U$9.IN, U$11.IN, U$12.IN, U$13.IN, U$14.IN, U$15.IN, U$16.IN, U$17.IN, U$18.IN, U$19.IN, U$20.IN, U$21.IN, U$22.IN, U$23.IN
COL1: U$2.30 (COL1), U$24.IN, U$25.IN, U$26.IN, U$27.IN, U$28.IN, U$29.IN, U$30.IN, U$31.IN, U$32.IN, U$33.IN, U$34.IN, U$35.IN, U$36.IN, U$37.IN, U$38.IN
COL2: U$2.31 (COL2), U$39.IN, U$40.IN, U$41.IN, U$42.IN, U$43.IN, U$44.IN, U$45.IN, U$46.IN, U$47.IN, U$48.IN, U$49.IN, U$50.IN, U$51.IN, U$52.IN
COL3: U$2.32 (COL3), U$54.IN, U$55.IN, U$56.IN, U$57.IN, U$58.IN, U$59.IN, U$60.IN, U$61.IN, U$62.IN, U$63.IN, U$64.IN, U$65.IN, U$66.IN, U$68.IN
COL4: U$2.33 (COL4), U$67.IN, U$69.IN, U$70.IN, U$72.IN, U$73.IN, U$75.IN, U$76.IN, U$77.IN, U$79.IN, U$81.IN
COL5: U$2.34 (COL5)
COL6: U$2.35 (COL6)
COL7: U$2.36 (COL7)
DRAIN: 15.1, Q1.3 (D), R11.1, R12.1, R13.1, R14.1, R16.1, R17.1, R18.1, R19.1, R20.1, U$78.P$1
GND: C1.2, C2.1, C3.2, LED1.1, LED2.1, LED3.1, LED4.1, LED5.1, LED6.1, LED7.1, LED8.1, LED9.1, LED10.1, PNP_DOWN.2, Q2.3 (C), U$1.2 (A1), U$1.3 (A2), U$1.4 (VSS), U$1.7 (WP), U$2.1 (GND), U$2.4 (GND), U$2.37 (TEST), U$2.THERMAL, U$2.VIA1 (THERMAL), U$2.VIA2 (THERMAL), U$2.VIA3 (THERMAL), U$2.VIA4 (THERMAL), U$2.VIA5 (THERMAL), U$3.1, U$3.P$2, U$80.P$1, VOLTAGE_REGULATOR.1 (GND)
INT18: Q2.2 (E), U$2.12 (INT), U$7.1, U$7.P$2
LED_GROUND0: LED11.2, R_LED0.2
LED_GROUND1: LED12.2, R_LED1.2
LED_GROUND2: LED13.2, R_LED2.2
unnamed: LED1.2, R11.2
unnamed: LED2.2, R12.2
unnamed: LED3.2, R13.2
unnamed: LED4.2, R14.2
unnamed: 15.2, LED5.2
unnamed: LED6.2, R16.2
unnamed: LED7.2, R17.2
unnamed: LED8.2, R18.2
unnamed: LED9.2, R19.2
unnamed: LED10.2, R20.2
unnamed: PNP_DOWN.1, PNP_UP.2, Q2.1 (B)
unnamed: LED12.1, U$2.7 (LED1), U$71.P$1
unnamed: LED11.1, U$2.6 (LED0), U$53.P$1
unnamed: LED13.1, U$2.8 (LED2), U$74.P$1
unnamed: PNP_DOWN1.2, U$1.1 (A0)
ROW0: U$2.15 (ROW0), U$9.OUT, U$24.OUT, U$39.OUT, U$54.OUT, U$69.OUT
ROW1: U$2.16 (ROW1), U$38.OUT, U$68.OUT
ROW2: U$2.17 (ROW2), U$11.OUT, U$25.OUT, U$40.OUT, U$55.OUT, U$70.OUT
ROW3: U$2.18 (ROW3), U$12.OUT, U$26.OUT, U$41.OUT, U$56.OUT, U$72.OUT
ROW4: U$2.19 (ROW4), U$13.OUT, U$27.OUT, U$42.OUT, U$57.OUT
ROW5: U$2.20 (ROW5), U$14.OUT, U$28.OUT, U$43.OUT, U$58.OUT, U$73.OUT
ROW6: U$2.21 (ROW6), U$15.OUT, U$29.OUT, U$44.OUT, U$59.OUT, U$75.OUT
ROW7: U$2.22 (ROW7), U$16.OUT, U$30.OUT, U$45.OUT, U$60.OUT
ROW8: U$2.23 (ROW8), U$17.OUT, U$31.OUT, U$46.OUT, U$61.OUT, U$76.OUT
ROW9: U$2.24 (ROW9), U$18.OUT, U$32.OUT, U$47.OUT, U$62.OUT, U$77.OUT
ROW10: U$2.25 (ROW10), U$19.OUT, U$33.OUT, U$48.OUT, U$63.OUT
ROW11: U$2.26 (ROW11), U$20.OUT, U$34.OUT, U$49.OUT, U$64.OUT, U$79.OUT
ROW12: U$2.27 (ROW12), U$21.OUT, U$35.OUT, U$50.OUT, U$65.OUT, U$81.OUT
ROW13: U$2.28 (ROW13), U$22.OUT, U$36.OUT, U$51.OUT, U$66.OUT
ROW14: U$2.40 (ROW14), U$23.OUT, U$37.OUT, U$52.OUT, U$67.OUT
ROW15: U$2.3 (ROW15)
SCL18: U$1.6 (SCL), U$2.11 (SCL), U$6.1, U$6.P$2
SDA18: U$1.5 (SDA), U$2.10 (SDA), U$5.1, U$5.P$2
VCC: C3.1, PNP_DOWN1.1, U$1.8 (VCC), U$2.38 (VCC), U$2.39 (VCC), VOLTAGE_REGULATOR.2 (VO)

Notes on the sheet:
TCA8424
CAT24C02
PNP

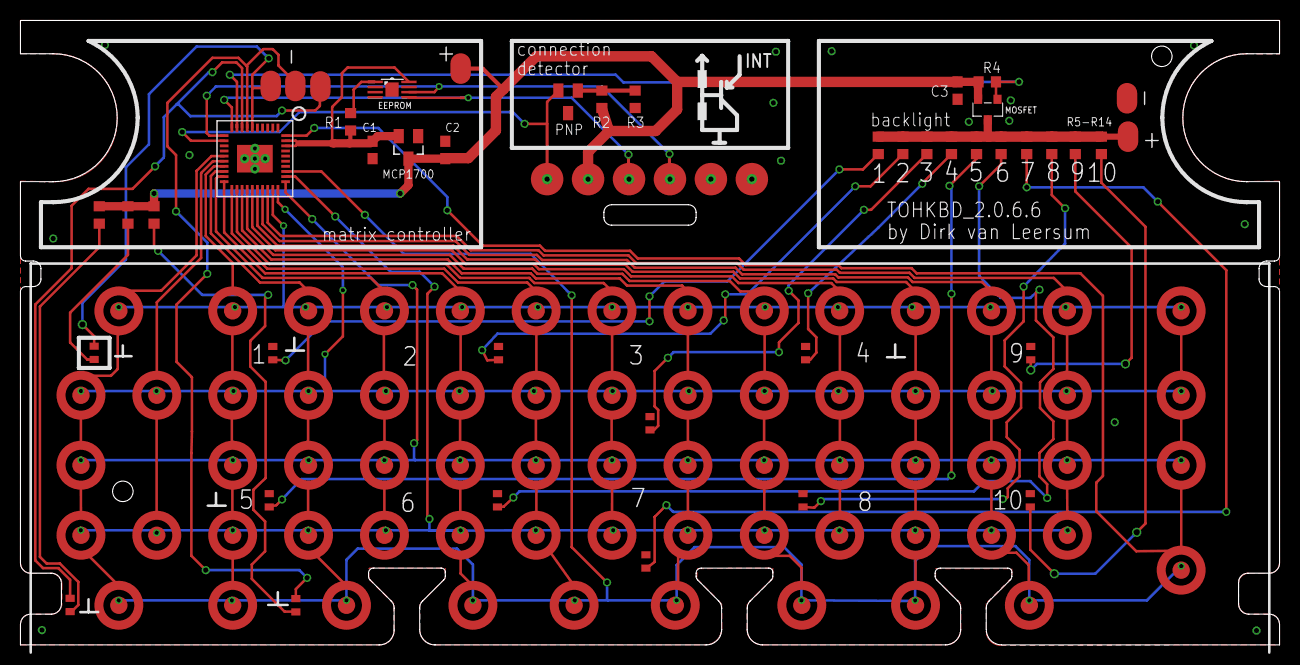
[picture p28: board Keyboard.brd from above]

Board: 2 copper layers, 123.0 x 61.0 mm, 117 parts (0 on the bottom side), 46 nets.

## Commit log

2015-02-21 CAD files
    [Keyboard.STL, TOH_casing.STL]
2015-03-08 pictures of bottom schematic
2015-03-17 Added FDM printer compatible models
    [KBD_back.stl, KBD_top.stl, casing.stl]
2015-03-17 added model for the bumps that go agains the alignment cavities in the KBD casing
    [bump.stl]
2015-04-05 Eagle files
    [Cover.brd, Cover.sch, Keyboard.brd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]
2015-06-06 pics and info
    [Cover.brd, Cover.sch]
2015-10-07 Add pogo pin part number to SMD part list
